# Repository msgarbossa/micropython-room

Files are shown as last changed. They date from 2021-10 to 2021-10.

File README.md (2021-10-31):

# micropython-room

This project uses MicroPython on ESP32 with an SSD1306 OLED and has a few options for I2C temperature sensors (BME280, ATH10).  ESP32's deep sleep is used with 2 wakeup sources, either by timer every 5 minutes or when the capacitive touch sensor is triggered.  The OLED only turns on when powered on or when the capacitive touch is triggered in order to limit light pollution in a dark room.  The anytemp module has a class to abstract different sensors to make them easier to swap since reading a temperature sensor tends to have the same interface.

## Diagram

2 separate I2C busses are used.  See [note about MicroPython and I2C](https://msgarbossa.github.io/documentation/MicroPython/libraries.html#note-about-micropython-and-i2c)

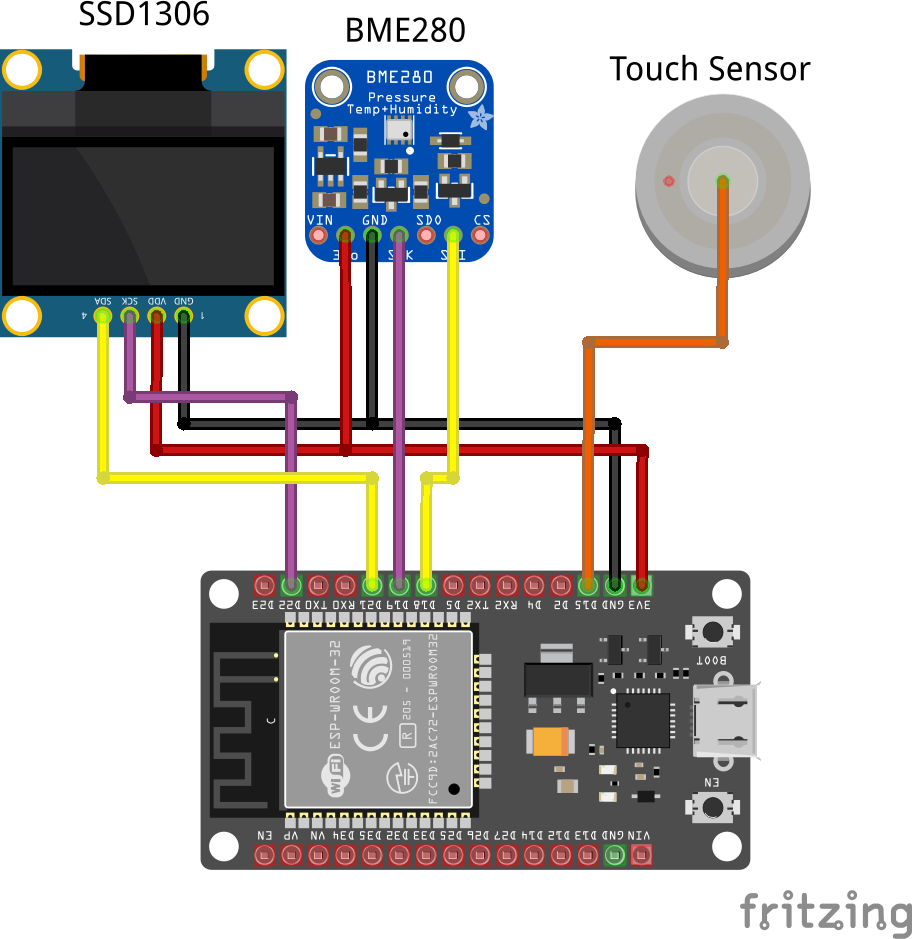
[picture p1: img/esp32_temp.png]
wiring diagram


## Using the code

- copy boot.py.sample to boot.py and update variables
- echo "PASS = 'password'" > webrepl_cfg.py
- [upload all *.py files](https://msgarbossa.github.io/documentation/MicroPython/ampy.html) to ESP32 controller [flashed with MicroPython](https://msgarbossa.github.io/documentation/MicroPython/flash_firmware.html)

## 3D printed case

See [3d-printed-case](./3d-printed-case) for STL and FreeCAD files

Images below are from older version running Arduino.  MicroPython's font only has the one small size.

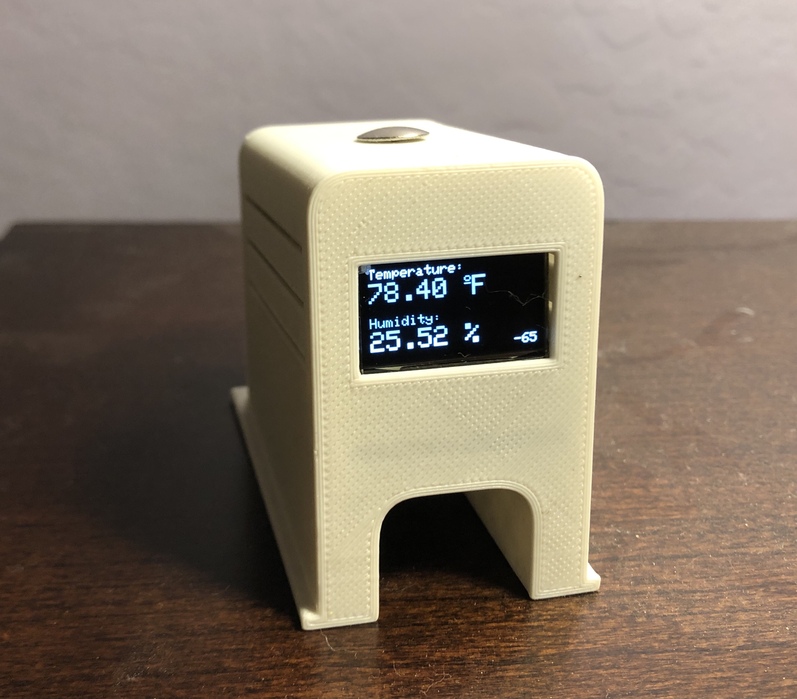
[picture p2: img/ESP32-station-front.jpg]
front


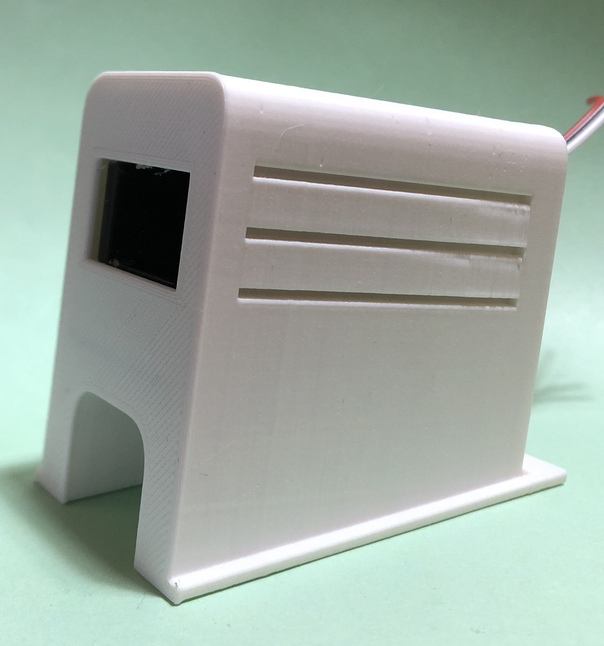
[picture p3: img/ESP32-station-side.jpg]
side


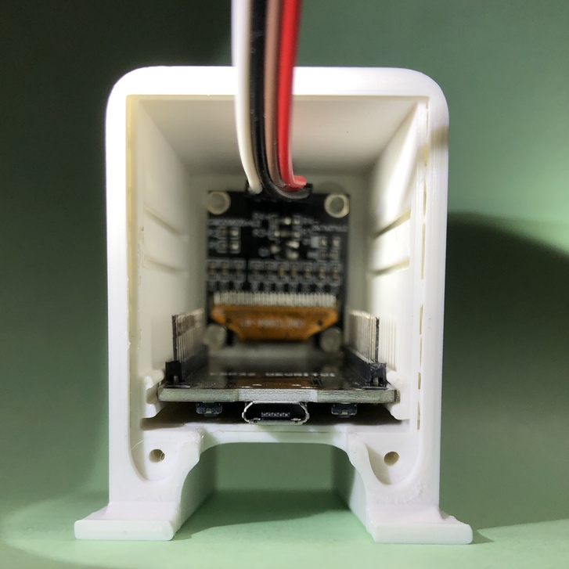
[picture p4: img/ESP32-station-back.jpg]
back


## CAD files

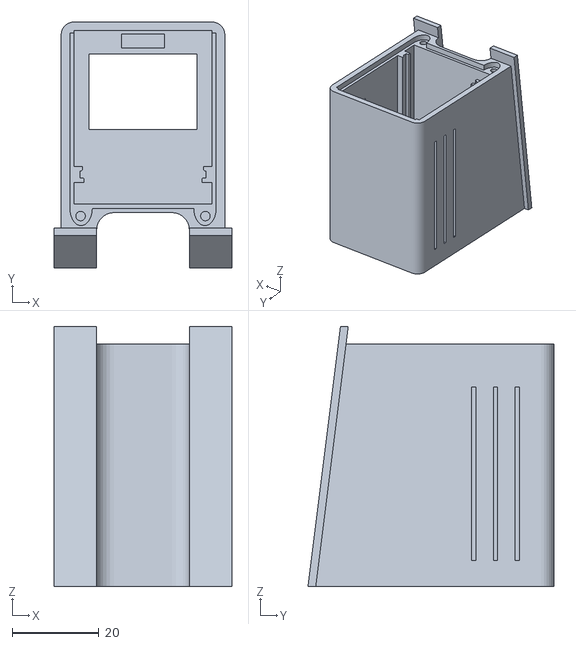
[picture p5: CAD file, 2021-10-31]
3d-printed-case/esp32-station-v1.0.0-main.stl
41.0 x 56.8 x 60.0

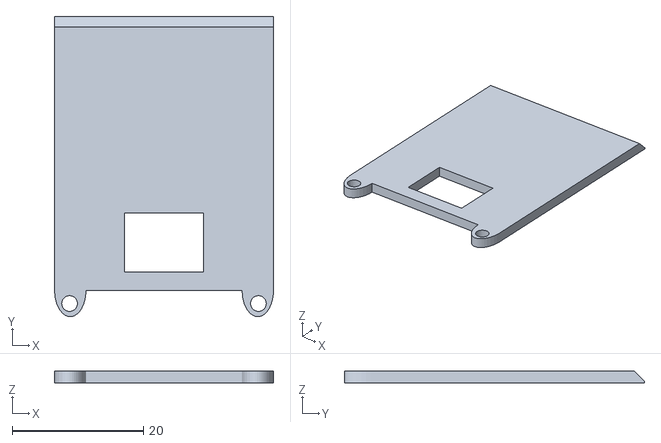
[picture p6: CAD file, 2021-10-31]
3d-printed-case/esp32-station-v1.0.0-cover.stl
33.4 x 45.8 x 1.80

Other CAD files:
3d-printed-case/esp32-station-v1.0.0.FCStd

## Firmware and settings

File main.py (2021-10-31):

from machine import Pin, ADC, Timer, RTC, TouchPad, deepsleep, I2C, SoftI2C
import esp32
from mqtt import MQTTClient 
import utime
import ssd1306
import webrepl
import time  # needed for ntptime
import network
import ubinascii
import anytemp

# Pins and pin configs
sdaPin = 21
sclPin = 22
sdaPinSoft = 18
sclPinSoft = 19
touchPin = 15
touchMaxValue = 250
led = Pin(2,Pin.OUT)  # for onboard LED blink
doDisplay = False
doPowerOn = False

# Wifi object
wlan = network.WLAN(network.STA_IF)

# MQTT
client_id = ubinascii.hexlify(machine.unique_id())
topic_sub = b'home/%s/cmd' % (dev_name)
topic_pub = b'home/%s/metrics' % (dev_name)

# metric variables
message_interval = 300  # duration of deep sleep
signal = 0
temperature_string = ""
humidity_string = ""
pressure_string = ""
status = ""

# I2C
# 60 (0x3c) = ssd1306, 118 (0x76) = bme280, 56 (0x38) = aht10
i2c = I2C(1, scl=Pin(sclPin), sda=Pin(sdaPin), freq=400000)
i2c_s = SoftI2C(sda=Pin(sdaPinSoft), scl=Pin(sclPinSoft))
# print(i2c.scan())  # to debug I2C
# print(i2c_s.scan())  # to debug SoftI2C

# Create dispay object using I2C
display = ssd1306.SSD1306_I2C(128, 64, i2c)
display.contrast(50)

# Crate AnyTemp object (abstraction for different temp sensors)
tempSensor = anytemp.AnyTemp(i2c_s, temp_sensor_model)

def wifi_connect(wifi_ssid,wifi_passwd):
  wlan.active(True)
  if not wlan.isconnected():
    print('\nConnecting to network', end='')
    wlan.connect(wifi_ssid, wifi_passwd)
    while not wlan.isconnected():
      print('.', end='')
      utime.sleep(0.5)
      pass
  print()
  print("Interface's MAC: ", ubinascii.hexlify(network.WLAN().config('mac'),':').decode()) # print the interface's MAC
  print("Interface's IP/netmask/gw/DNS: ", wlan.ifconfig(),"\n") # print the interface's IP/netmask/gw/DNS addresses

def sub_cb(topic, msg):
  # print((topic, msg))
  last_receive = utime.time()
  print('%s: received message on topic %s with msg: %s' % (last_receive, topic, msg))
  if topic == topic_sub and msg == b'ping':
    client.publish(topic_pub, b'pong')
    print('sent pong')

def connect_and_subscribe():
  global client_id, mqtt_server, topic_sub
  client = MQTTClient(client_id, mqtt_server, port=1883, user=mqtt_user, password=mqtt_password)
  client.set_callback(sub_cb)
  client.connect()
  client.subscribe(topic_sub)
  print('Connected to %s MQTT broker, subscribed to %s topic' % (mqtt_server, topic_sub))
  return client

def restart_and_reconnect():
  print('Failed to connect to MQTT broker. Reconnecting...')
  utime.sleep(10)
  machine.reset()

def blink():
    led.on()
    utime.sleep_ms(500)
    led.off()
    utime.sleep_ms(500)

def draw_display():
  display.fill(0)  # clear display by filling with black
  display.rect(0, 0, 128, 64, 1)
  display.hline(0, 50, 128, 1)
  display.text(status, 2, 54, 1)
  if temperature_string:
    temperature_display = temperature_string + ' F'
    display.text(temperature_display, 2, 4, 1)
  if humidity_string:
    humidity_display = humidity_string + ' %'
    display.text(humidity_display, 2, 18, 1)
  if pressure_string:
    display.text(pressure_string, 2, 32, 1)
  retry = 3
  while retry > 0:
    try:
      display.show()
      break
    except:
      print("retry display (usually I2C timeout when waking from capacitive touch")
      utime.sleep(0.5)
      retry -= 1
      continue

def wait_for_sensor(sleep_sec):
  global status
  print('wait %s seconds on start' % (sleep_sec))
  while sleep_sec > 0:
    status = 's={0}, sleep {1}'.format(signal, sleep_sec)
    # draw_status(status)
    draw_display()
    utime.sleep(1)
    sleep_sec -= 1

def get_metrics():

  # variables used in display (TODO: pass w/ kwargs)
  global temperature_string
  global humidity_string
  global pressure_string
  global status
  global signal

  tempSensor.read()
  temperature_val = tempSensor.temperature
  humidity_val = tempSensor.humidity
  pressure_string = tempSensor.pressure

  temperature_string = "{:0.1f}".format(round(temperature_val, 1))
  humidity_string = "{:0.1f}".format(round(humidity_val, 1))

  print(temperature_string)
  print(humidity_string)
  print(pressure_string)

def display_metrics():
  status = 's={0}'.format(signal)
  display.poweron()
  draw_display()
  utime.sleep(8)

def send_metrics(mqtt_client):
  if pressure_string:
    # msg = b'{{"s":"{0}","t":"{1}","h":"{2}","p":"{3}"}}'.format(signal, temperature_string, humidity_string, pressure_string)
    msg = b'{{"s":"{0}","t":"{1}","h":"{2}"}}'.format(signal, temperature_string, humidity_string)
  else:
    msg = b'{{"s":"{0}","t":"{1}","h":"{2}"}}'.format(signal, temperature_string, humidity_string)
  blink()
  mqtt_client.publish(topic_pub, msg)
  print('MQTT: published metrics')

def do_deepsleep():
  # to calibrate or debug TouchPad (determine touchMaxValue to use for wakeup)
  # t = TouchPad(Pin(touchPin))
  # print(t.read()) # smaller number when touched

  wake = Pin(touchPin, mode = Pin.IN)
  touch = TouchPad(wake)
  touch.config(touchMaxValue)
  esp32.wake_on_touch(True)
  print('deep sleep for {0}s'.format(message_interval))
  deepsleep(1000 * message_interval)  # ms to sleep

# check how the ESP32 was started up (mainly by touch sensor, hard power on, soft reboot)
boot_reason = machine.reset_cause()
if boot_reason == machine.DEEPSLEEP_RESET:
  print('woke from a deep sleep')  # constant = 4
  wake_reason = machine.wake_reason()
  print("Device running for: " + str(utime.ticks_ms()) + "ms")
  print("wake_reason: " + str(wake_reason))
  if wake_reason == machine.PIN_WAKE:
      print("Woke up by external pin (external interrupt)")
  elif wake_reason == 4:  # machine.RTC_WAKE, but constant doesn't exist
      print("Woke up by RTC (timer ran out)")
  elif wake_reason == 5:  # machine.ULP_WAKE, but constant doesn't match
      print("Woke up capacitive touch")
      doDisplay = True
elif boot_reason == machine.SOFT_RESET:
  print('soft reset detected')  # constant = 5
elif boot_reason == machine.PWRON_RESET:
  print('power on detected') # constant = 1
  # This is used for 2 main reasons:
  # 1. Safety net in case there are issues with deep sleep that makes it difficult to re-upload
  # 2. Often the sensors need a few seconds to get accurate readings when power is first applied
  #    except deep sleep should cut power on the regulated 3.3V pin, but not 5Vin
  doPowerOn = True
  signal = 'NA'
  wait_for_sensor(5)
elif boot_reason == machine.WDT_RESET:
  print('WDT_RESET detected') # constant = 3
  # This also seems to indicate a hard power on
  doPowerOn = True
  signal = 'NA'
  wait_for_sensor(5)
else:
  print('boot_reason={0}'.format(boot_reason))

get_metrics()
if doDisplay:
  display_metrics()

wifi_connect(ssid, password)
signal = wlan.status('rssi')
webrepl.start()

# Give extra time on first boot in case webrepl is needed
if doPowerOn:
  wait_for_sensor(25)

# Connect to MQTT
try:
  client = connect_and_subscribe()
except OSError as e:
  restart_and_reconnect()

client.check_msg()
send_metrics(client)
print("Device running before sleep: " + str(utime.ticks_ms()) + "ms")

display.fill(0)  # clear display by filling with black
display.poweroff() # power off the display, pixels persist in memory
do_deepsleep()

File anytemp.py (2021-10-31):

class AnyTemp:

    temperature = 0
    humidity = 0
    pressure = 0

    # instance attribute
    def __init__(self, i2c, model):
        self.model = model
        if model == "bme280":
            import BME280
            self.temp_obj = BME280.BME280(i2c=i2c)
        elif model == "aht10":
            import ahtx0
            self.temp_obj = ahtx0.AHT10(i2c)
        
    def read(self):
        if self.model == "bme280":
            self.temperature = (self.temp_obj.read_temperature()/100) * (9/5) + 32
            self.humidity = self.temp_obj.read_humidity()/1000
            self.pressure = self.temp_obj.pressure
        elif self.model == "aht10":
            self.temperature = self.temp_obj.temperature * (9/5) + 32
            self.humidity = self.temp_obj.relative_humidity
